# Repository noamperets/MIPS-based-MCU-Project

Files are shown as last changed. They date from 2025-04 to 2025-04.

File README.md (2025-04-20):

# MIPS-Based MCU Architecture and Design

Final project for the Advanced Microprocessor Architecture and Hardware Accelerators Lab Course 

## 📘 Project Overview

This project implements a **Microcontroller Unit (MCU)** architecture based on a MIPS CPU core.  
The design includes peripherals such as a basic timer, GPIO, interrupt controller, and an optimized address decoder — all written in VHDL.

📝 For full documentation and RTL schematics, see the [PDF Report](./DOC/final.pdf).

## 📁 Project Structure

Below is a list of the main VHDL modules with short functional descriptions:

### 🔷 CPU Components

- **`MIPS.vhd`** – The full MIPS CPU core: fetch, decode, execute, memory access, and writeback.
- **`IFETCH.vhd`** – Instruction fetch stage.
- **`IDECODE.vhd`** – Instruction decode and control signal generation.
- **`EXECUTE.vhd`** – ALU logic, branch and jump decisions.
- **`CONTROL.vhd`** – Generates control signals based on instruction opcode.
- **`DMEMORY.vhd`** – Data memory access.

### 🔷 MCU Components

- **`MCU.vhd`** – Top-level design connecting CPU and peripherals.
- **`Optimized_Addr_Decoder.vhd`** – Maps 5-bit address inputs to 12-bit chip select lines for peripherals.
- **`GPIO.vhd`** – Drives LEDs and HEX displays; handles memory-mapped I/O.
- **`HexDecoder.vhd`** – Converts 4-bit binary values to 7-segment display.
- **`BasicTimer.vhd`** – Timer module with interrupt generation and PWM-style output.
- **`freqdiv.vhd`** – Frequency divider generating mclk2, mclk4, and mclk8.
- **`InterruptController.vhd`** – Manages multiple interrupt sources (timer, keys) with prioritization.

## 💡 Key Features

- Modular MIPS-based processor architecture
- Memory-mapped I/O (LEDs, switches, hex displays)
- Custom interrupt controller with hardware-generated signals
- Peripheral integration via chip-select decoding
- Signal-level simulation in ModelSim and real-time testing using Quartus SignalTap

## 🔬 Results & Testing

- ✅ Verified waveforms using **ModelSim**
- ✅ Measured system response using **Quartus SignalTap**
- 📈 Achieved expected `fmax` and identified the **critical path** from the MIPS core to the GPIO write logic

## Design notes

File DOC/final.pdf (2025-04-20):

המחלקה להנדסת חשמל ומחשבים

אוניברסיטת בן-גוריון בנגב

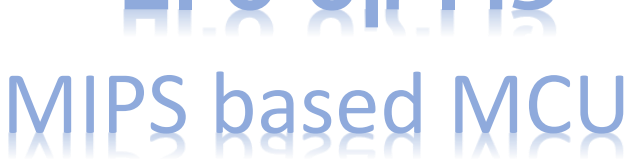
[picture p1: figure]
MIPS based MCU

### שמות המגישים והעורכים:

### נועם פרץ, נעם וקנין

### המחלקה להנדסת חשמל – קורס מעבדת ארכיטקטורת מעבדים מתקדמת ומאיצי חומרה

### תאריך הגשת הדו "ח: 08.08.23

# פרויקט סיום

# תוכן עניינים

3 | MCU Top level block | .1
4 | Blocks in top level design | .2
15 | Critical Path and Fmax | .3
16 | Waveform ModelSim | .4
18 | Waveform Quartus Signal Tap | .5

## MCU block diagram

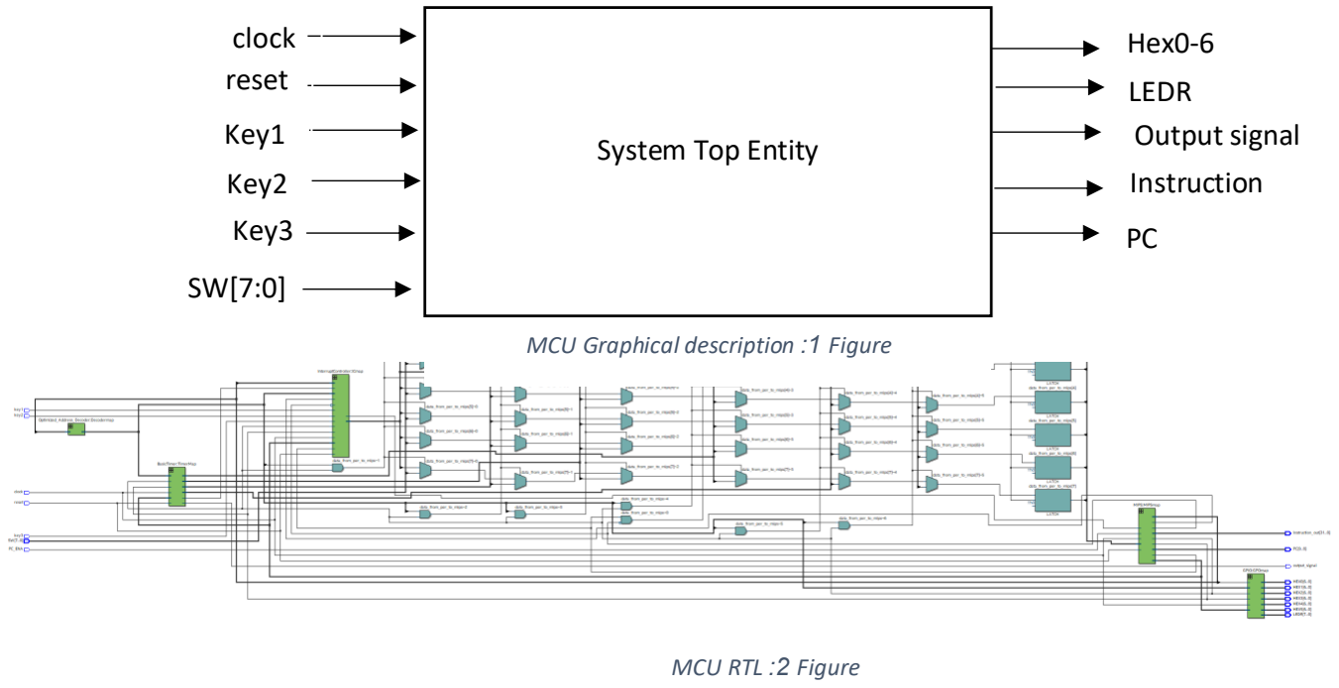
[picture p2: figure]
MCU RTL :2 Figure; System Top Entity; clock reset; Hex0-6; Key1; Key2; Key3; LEDR Output signal; Instruction; MCU Graphical description :1 Figure
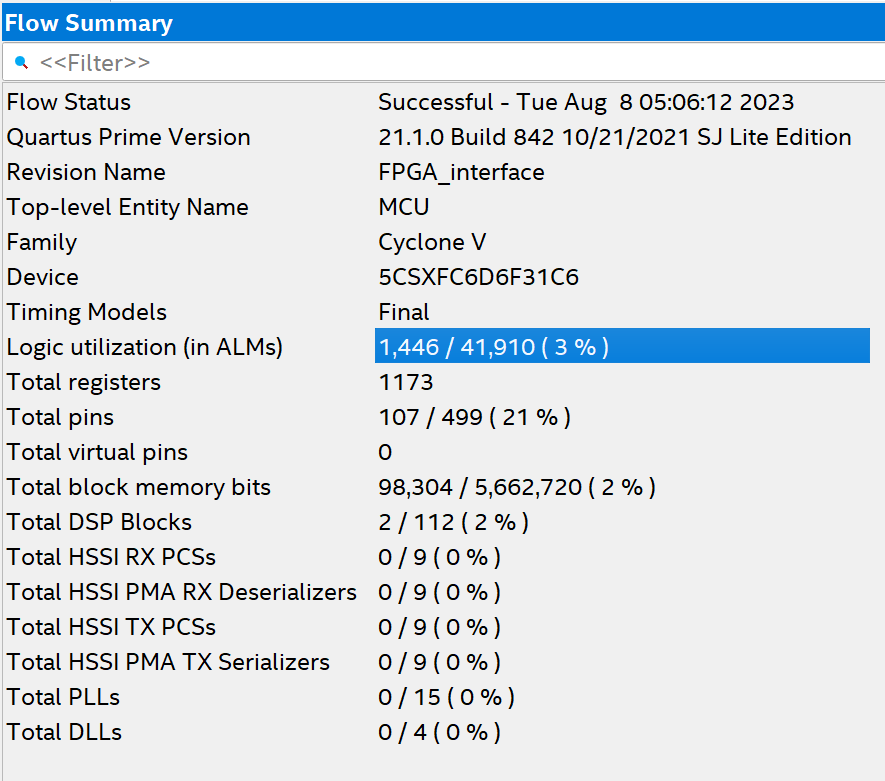
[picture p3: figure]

MCU Logic Usage :3 Figure

## MIPS block diagram

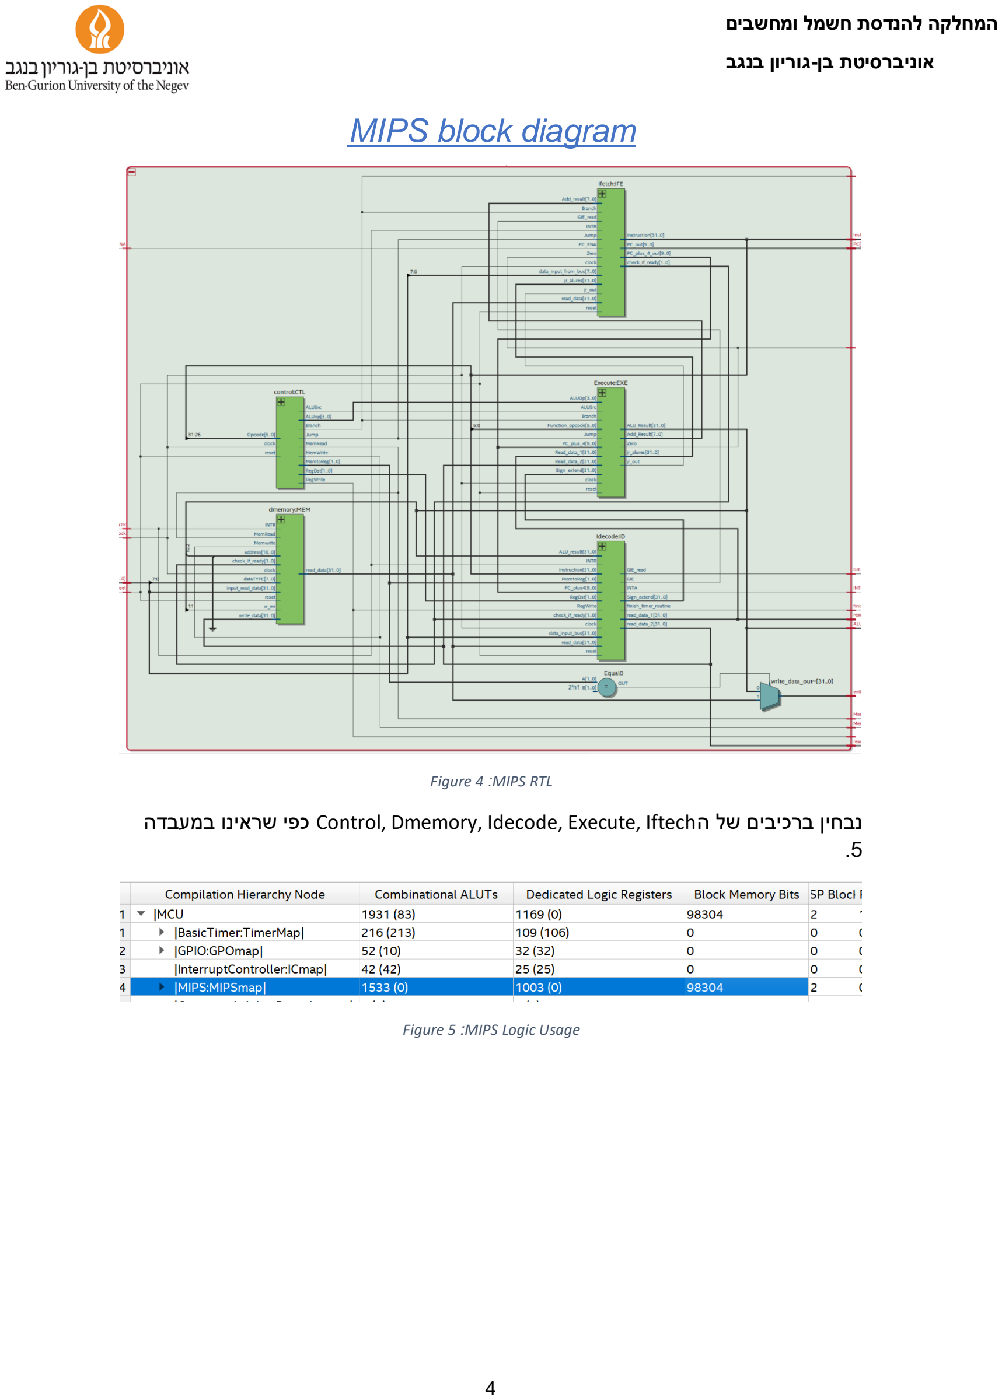
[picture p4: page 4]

Figure 4 :MIPS RTL

נבחין ברכיבים של הIftech ,Execute ,Idecode ,Dmemory ,Control כפי שראינו במעבדה .5

Figure 5 :MIPS Logic Usage

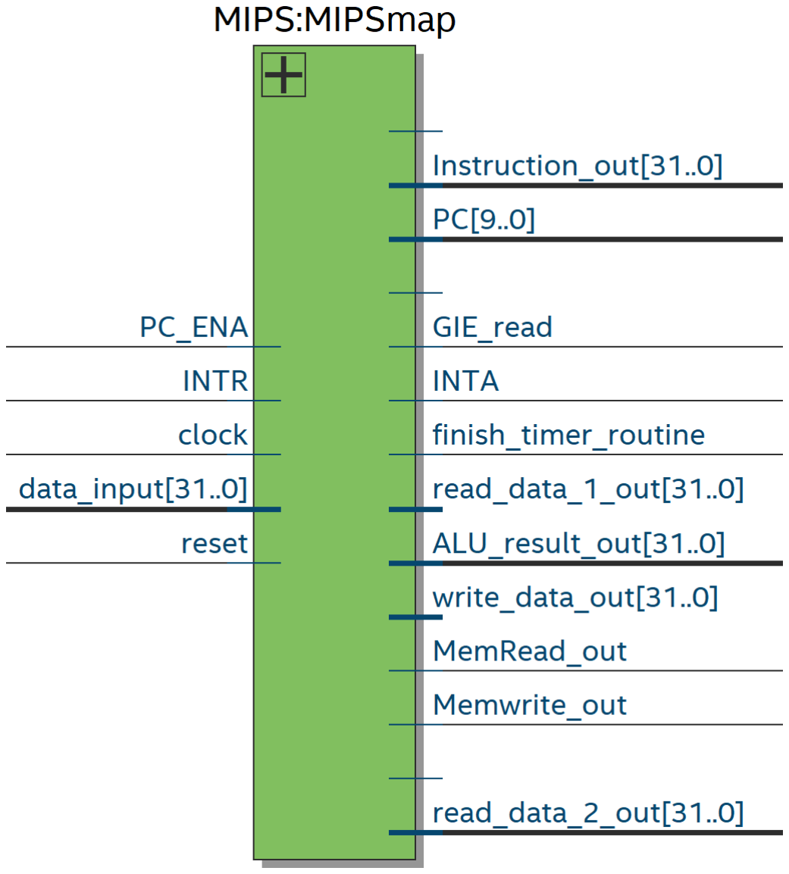
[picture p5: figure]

MIPS Graphical description :6 Figure

מודול זה זהו הליבה של המעבד )Core CPU), אחראית לרכיבים שתיארנו למעלה תוך גישה ל2 מרחבי זיכרון, של הפקודות )mem program )ושל המידע )mem data). מוציאה החוצה את ערך הdata הנוכחי בעת כתיבה לרכיבים הפריפריילים.

יחד עם זאת כל הרכיבים מאזינים לכתובת שיוצאת מרכיב ולאותות הבקרה של כתיבה וקריאה.

:Port Table

Port Name | Direction | Size | Functionality
PC | OUT | 10 bit | Program Counter output
ALU_result_out | OUT | 32 bit | ALU output
Read_data_1_out | OUT | 32 bit | Output read data 1
Read_data_2_out | OUT | 32 bit | Output read data 2
Write_data_out | OUT | 32 bit | Output of data to be written
Instruction_out | OUT | 32 bit | Output of instruction
reset | IN | bit | reset
clock | IN | bit | clock
Branch_out | OUT | bit | Output indicating branch condition
Zero_out | OUT | bit | Zero condtion

Memwrite_out | OUT | bit | Memory write operation
Regwrite_out | OUT | bit | Register write operation
PC_ENA | IN | bit | Enable signal for PC
MemRead_out | OUT | bit | Indicating memory read operation
Data_input | IN | 32 bits | Input data from the bus
GIE_read | OUT | Bit | Output indicating GIE status
INTR | IN | Bit | Interrupt request input
INTA | OUT | 1 bit | Interrupt acknowledge output
Finish_timer_routine | OUT | bit | Output indicating completion of timer routine

MIPS Port Table :Figure 7

## GPIO block diagram

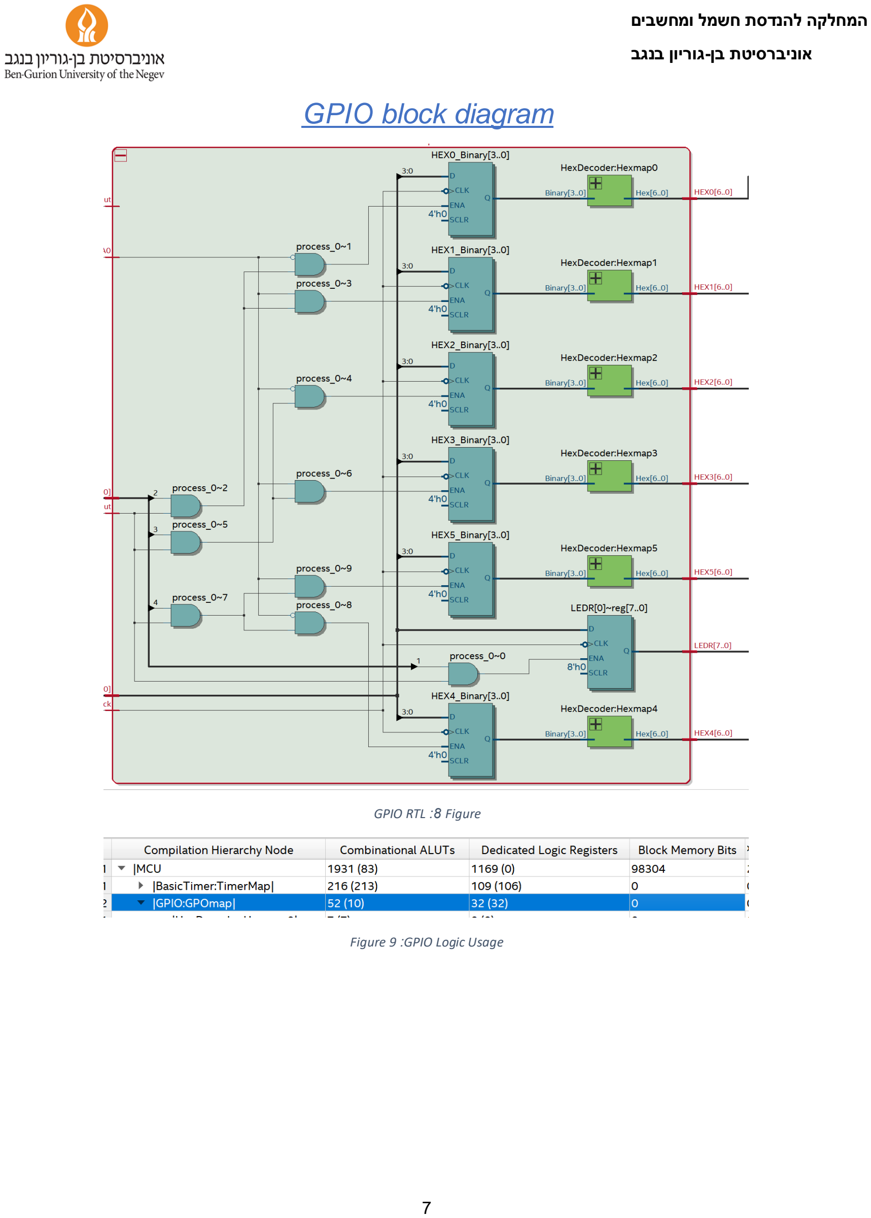
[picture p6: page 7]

GPIO RTL :8 Figure

Figure 9 :GPIO Logic Usage

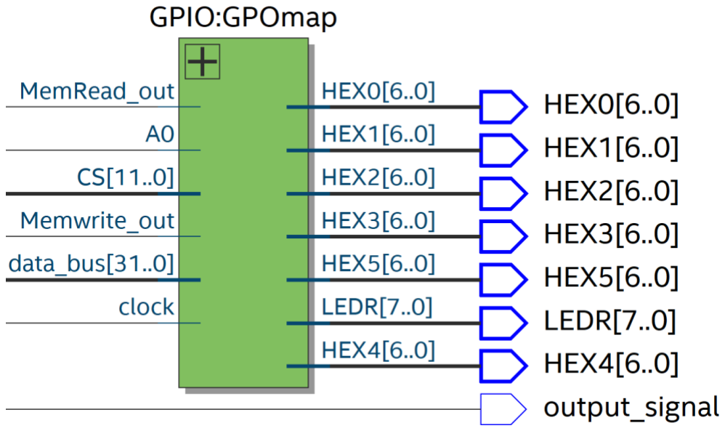
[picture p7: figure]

Figure 10 :GPIO Graphical description

בעזרת רכיב זה נכתוב להקסות )בעזרת HexDecoder )וללדים ע"י צ'יפ סלקט כפי שתואר במטלה.

:Port Table

Port Name | Direction | Size | Functionality
CS | IN | 12 bit | Chip select input
A0 | IN | Bit | Address bit 0 input
MemRead_out | IN | Bit | Memory read signal input
Memwrite_out | IN | Bit | Memory write signal input
Data_bus | IN | 32 bit | Data bus input
LEDR | OUT | 8 bit | LED outputs for display
HEX0-HEX5 | OUT | 7 bits each | Seven-segment display outputs
Clock | IN | Bit | Clock
GPIO Port Table :Figure 11

## Interrupt Controller block diagram

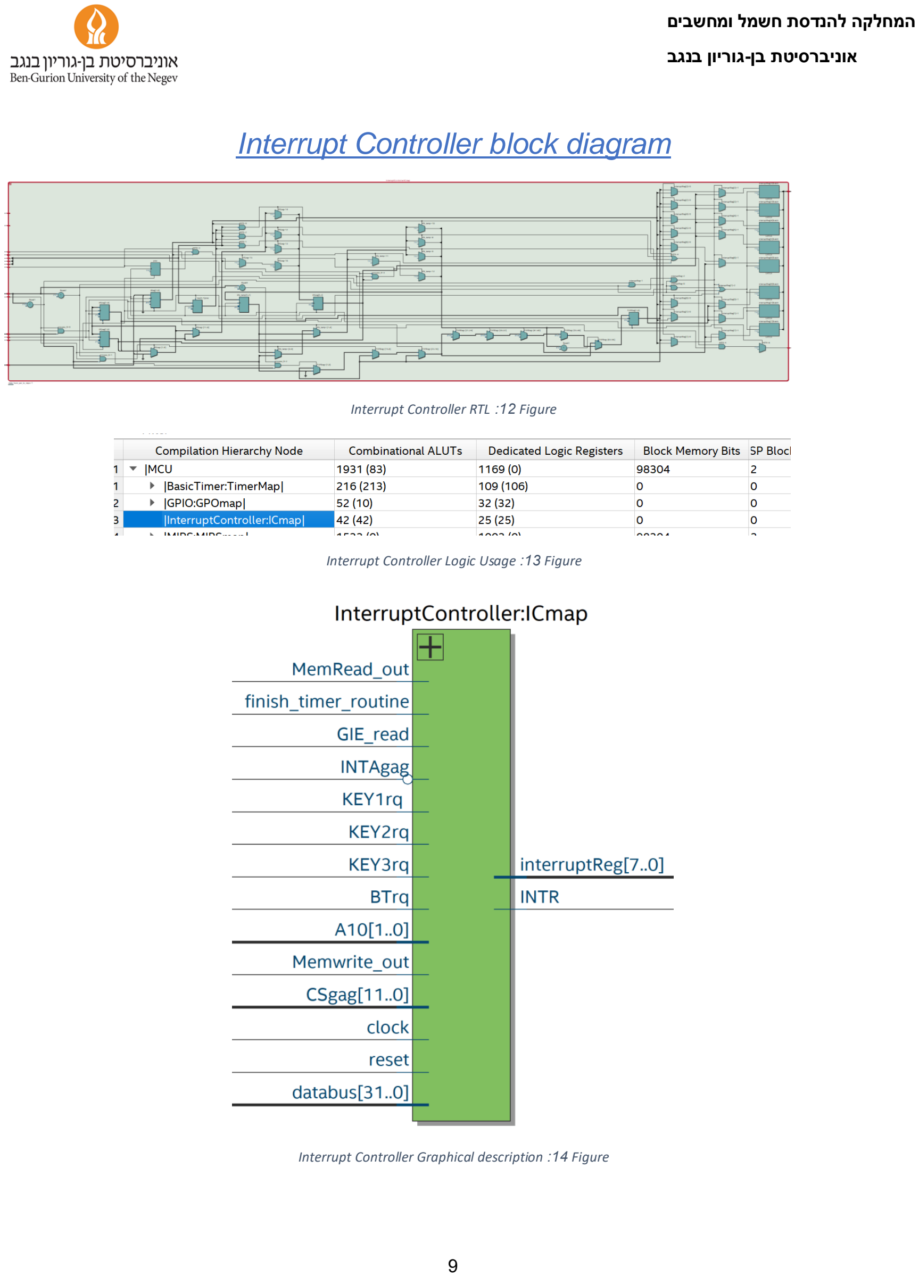
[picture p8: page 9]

Interrupt Controller RTL :12 Figure

Interrupt Controller Logic Usage :13 Figure

Interrupt Controller Graphical description :14 Figure

רכיב זה אחראי למנגנון הפסיקות, הוצאת הביט INTR לCPU בעת פסיקה וקבלת ̅̅̅̅̅̅̅ TNI כאשר הפסיקה התקבלה. פסיקה יכולה להיות מהטיימר או מהKeys. בנוסף הוא אחראי לדאוג לעדיפות הפסיקות.

:Port Table

Port Name | Direction | Size | Functionality
Clock | IN | Bit | Clock input
Reset | IN | Bit | Reset input
CSgag | IN | 12 bit | Complement of chip select input
BTrq | IN | Bit | BasicTimer interrupt request input
Key1rq | IN | Bit | KEY1 interrupt request input
Key2rq | IN | Bit | KEY2 interrupt request input
Key3rq | IN | Bit | KEY3 interrupt request input
INTAgag | IN | Bit | Complement of interrupt acknowledge input
INTR | OUT | Bit | Interrupt request output
Databus | IN | 32 bit | Data bus input
A10 | IN | 2 bit | Address bits A1-A0 input
GIE_read | IN | Bit | GIE read input
interruptReg | OUT | 8 bit | Interrupt flag, interrupt enable, type output
MemRead_out | IN | Bit | Memory read input
Memwrite_out | IN | Bit | Memory write input
Finish_timer_routine | IN | bit | Input indicating completion of timer routine

Interrupt Controller Port Table :Figure 15

## Basic Timer block diagram

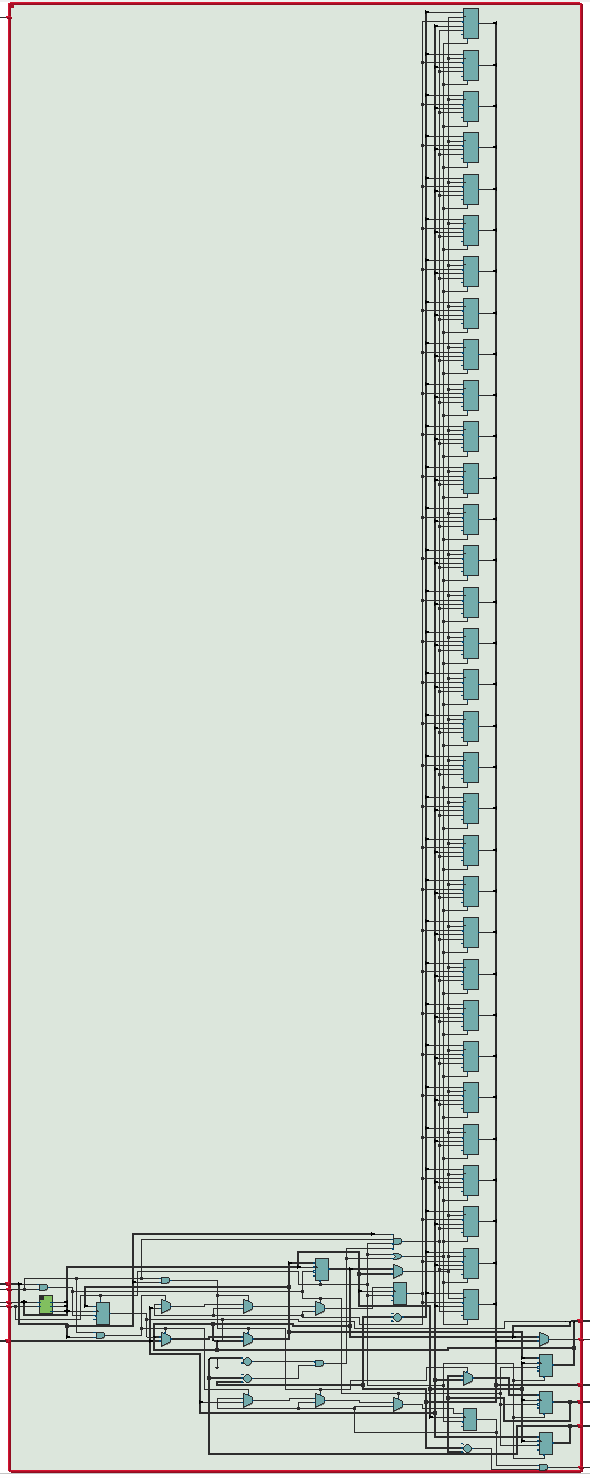
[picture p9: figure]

Figure 16 :Basic Timer RTL

BasicTimer Logic usage :17 Figure

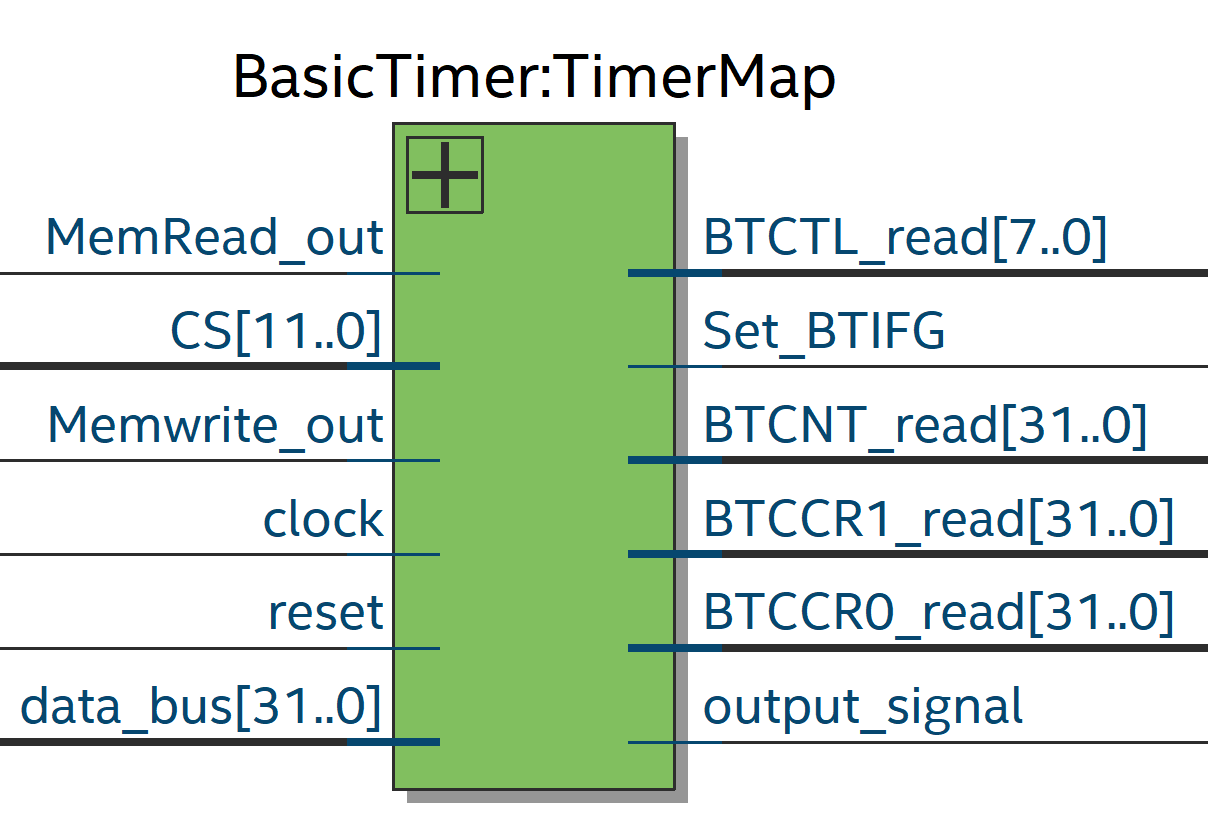
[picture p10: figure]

Basic Timer Graphical description :18 Figure

רכיב זה אחראי להוציא פסיקות ע"י הביט BTIFG_Set ולהוציא אות PWM לפי מנייה עולה כפי שתואר במטלה.

:Port Table

Port Name | Direction | Size | Functionality
Clock | IN | Bit | Clock input
Reset | IN | Bit | Reset input
CS | IN | 12 bit | chip select input
BTCTL_read | OUT | 8 bit | BT control register read output
BTCCR0_read | OUT | 32 bit | BT compare register 0 read output
BTCCR1_read | OUT | 32 bit | BT compare register 1 read output
BTCNT_read | OUT | 32 bit | Current count value read output
MemRead_out | IN | Bit | Memory read input
Memwrite_out | IN | Bit | Memory write input
Databus | IN | 32 bit | Data bus input
Output_signal | OUT | Bit | Output signal based on duty cycle
Set_BTIFG | OUT | bit | Output to set BTIFG interrupt flag

BasicTimer Port Table :Figure 19

## Optimized Address Decoder block diagram

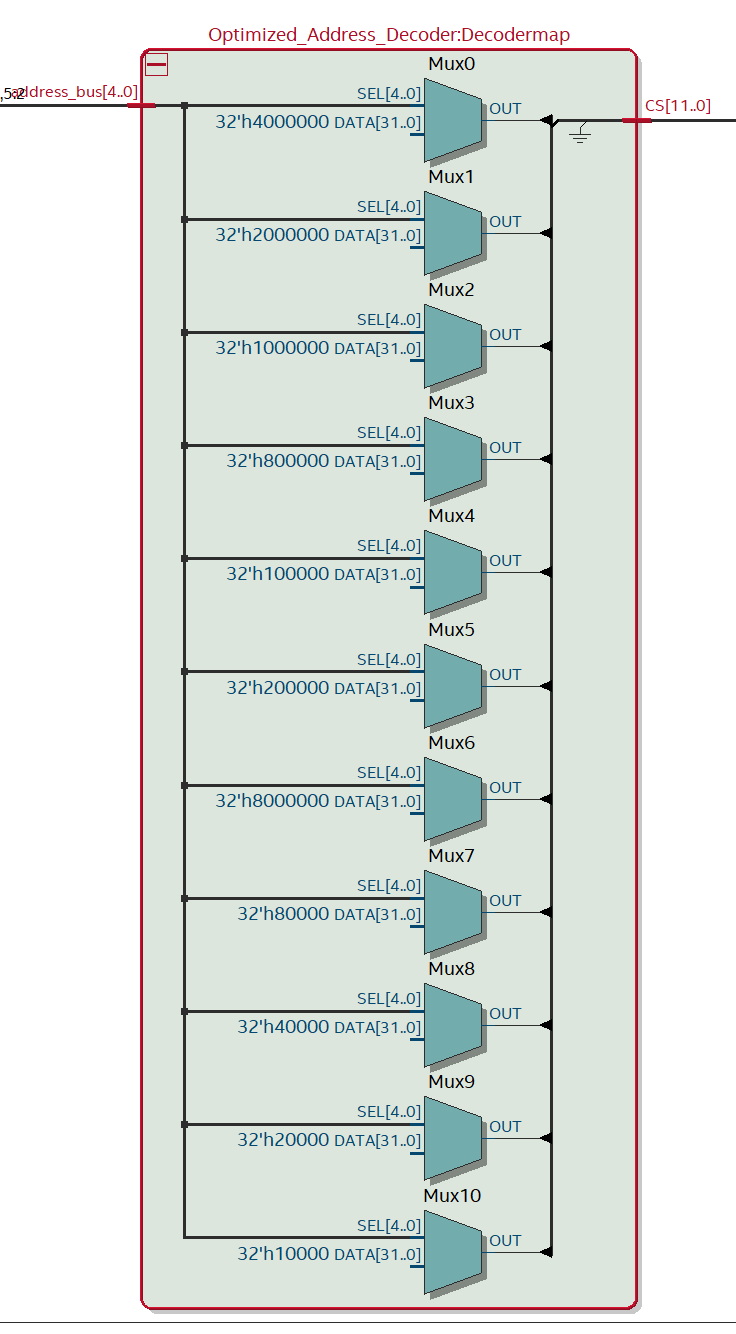
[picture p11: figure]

Optimized Address Decoder RTL :20 Figure

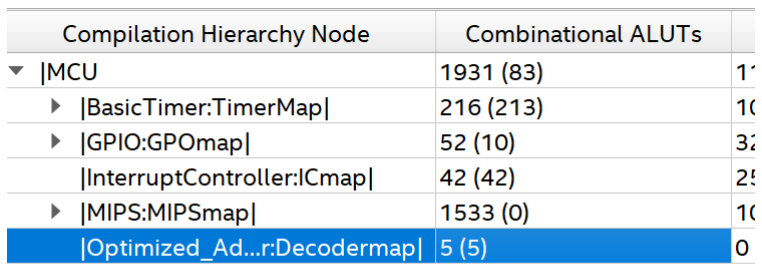
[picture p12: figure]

Optimized Address Decoder Logic usage :21 Figure

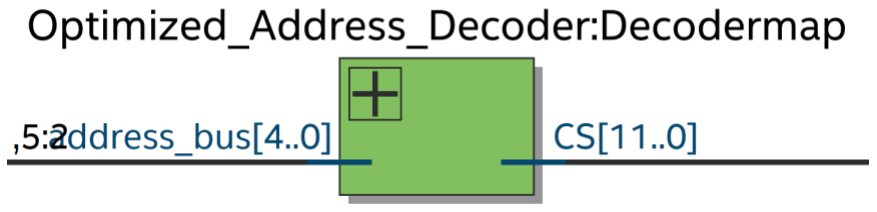
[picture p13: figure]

Figure 22 :Optimized Address Decoder Graphical description

רכיב זה מקבל כתובת ומקודד אותו לצ'יפ סלקט.

:Port Table

Port Name | Direction | Size | Functionality
Address_bus | IN | 5 bits | Address bus input
CS | OUT | 12 bits | CS outputs
Optimized Address Decoder :Figure 23

## Critical Path and fmax

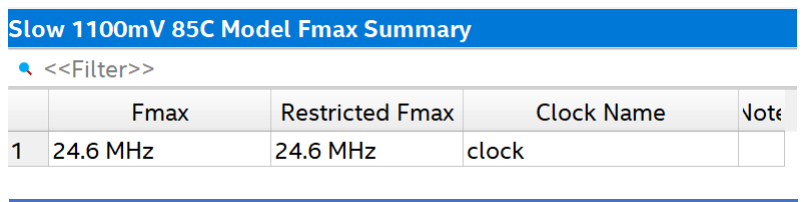
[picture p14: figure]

Maximum clock frequency :24 Figure

Figure 25 :MCU Critical Path

נשים לב שהמסלול הקריטי הוא במעבר בכל התחנות בMIPS ושליחת המידע למודול של הGPIO( לכתיבה(, קיבלנו תוצאה הגיונית.

## Waveform ModelSim

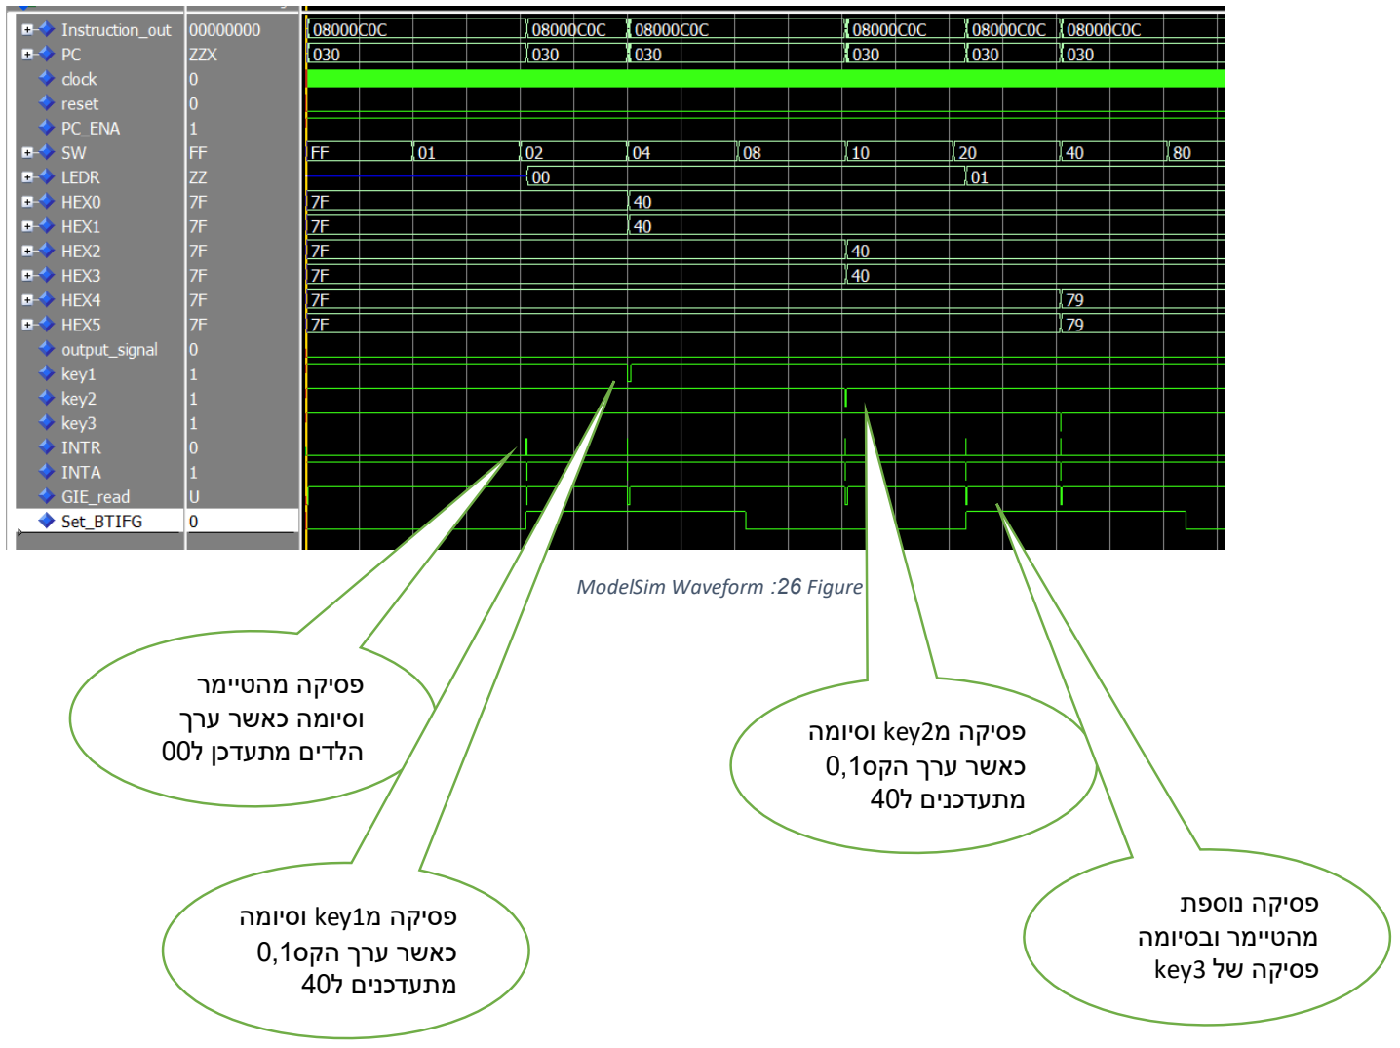
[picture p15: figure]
ModelSim Waveform :26 Figure; פסיקה מהטיימר וסיומה כאשר ערך הלדים מתעדכן ל00; פסיקה מ1key וסיומה כאשר ערך הקס0,1 מתעדכנים ל40; פסיקה מ2key וסיומה כאשר ערך הקס0,1 מתעדכנים ל40; פסיקה נוספת מהטיימר ובסיומה פסיקה של 3key

ניתן לראות שאכן לאחר כל פסיקה הPC חוזר לכתובת שממנה יצא לפסיקה. וכל פסיקה מתבצעת כראוי כך שפסיקה . נראה זאת גם בTap Signal.

## Waveform Quartus Signal Tap

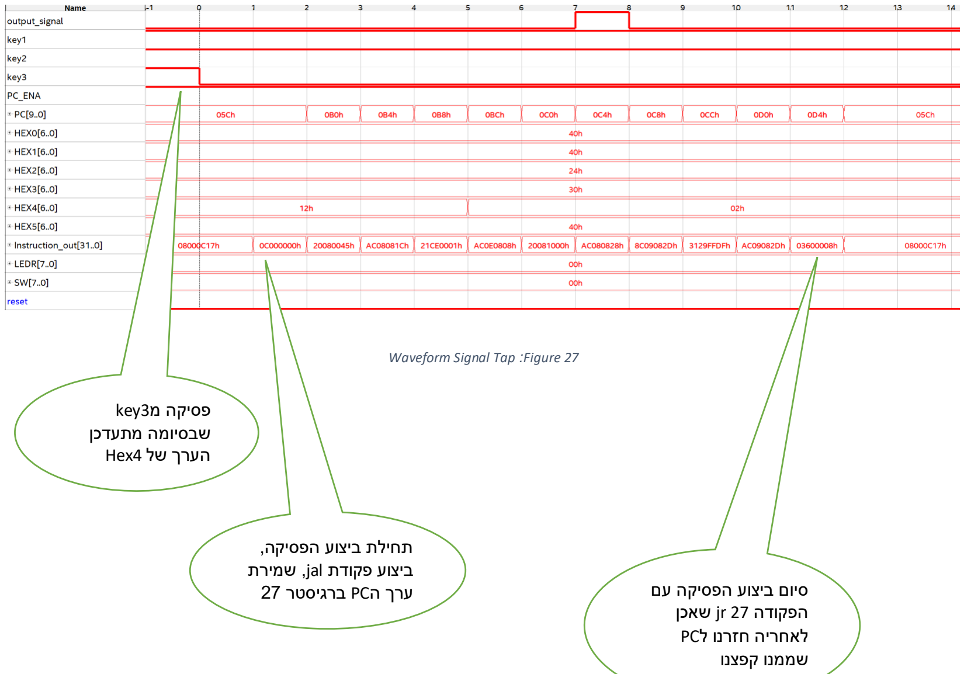
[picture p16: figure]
Waveform Signal Tap :Figure 27; פסיקה מ3key שבסיומה מתעדכן הערך של 4Hex; תחילת ביצוע הפסיקה, ביצוע פקודת jal, שמירת סיום ביצוע הפסיקה עם ערך הPC ברגיסטר 27 הפקודה 27 jr שאכן לאחריה חזרנו לPC שממנו קפצנו

בנוסף נוכל להבחין בlatency של 2 מחזורי שעון מרגע לחיצת הכפתור לפסיקה ועד אחרי פקודה הjal. וlatency של מחזור אחד בחזרה בפקודת 27 jr.

לסיכום, בעזרת פרויקט זה למדנו כיצד מחברים ומתפעלים רכיבים פריפריילים, IO, לליבת הMIPS שבנינו. בנוסף התמקצענו במימוש פסיקות מרכיבים אלה בעזרת ה- Interrupt
.INTR, INTA | הפסיקות | וקווי | Controller

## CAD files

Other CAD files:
Quartus/stp1.stp
